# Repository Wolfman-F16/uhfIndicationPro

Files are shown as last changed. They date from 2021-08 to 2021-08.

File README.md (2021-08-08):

# UHF Indication Board Pro
This board and firmware can be used standalone or with the UHF Control Board RP.
The full potential is, of course, unlocked with the UHF Control Board RP.

The board can be communicated with using SPI, UART or I2C (not implemented).

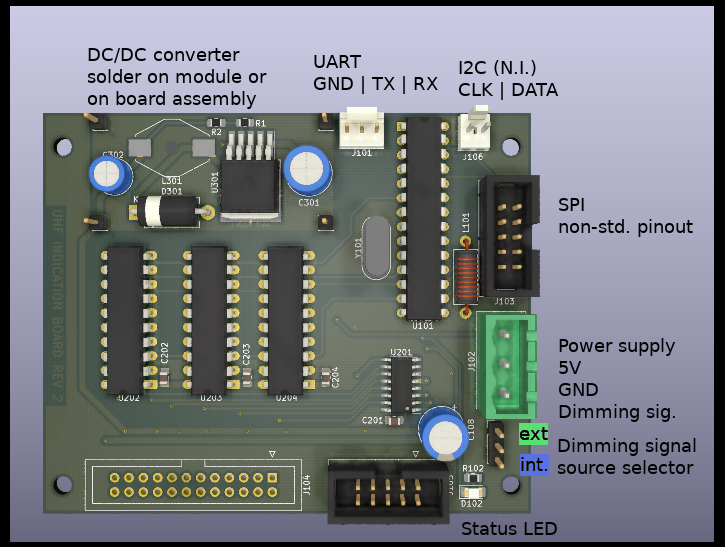
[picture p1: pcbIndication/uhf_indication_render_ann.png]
board with annotations


# AVR Fuse Bits
Use your ISP programmer of choice to set the fuse bits of the ATmega8 microcontroller. ATTENTION: the pinout of the board is not standard! Make sure you have a modified ribbon cable or use jumper wires to make the appropriate connections!

    avrdude -c <programmer> -p m8 -Ulfuse:v:0xfe:m -Uhfuse:v:0xd1:m

# Flashing Firmware

    avrdude -c <programmer> -p m8 -Uflash:v:UhfIndicationPro.<version>.hex

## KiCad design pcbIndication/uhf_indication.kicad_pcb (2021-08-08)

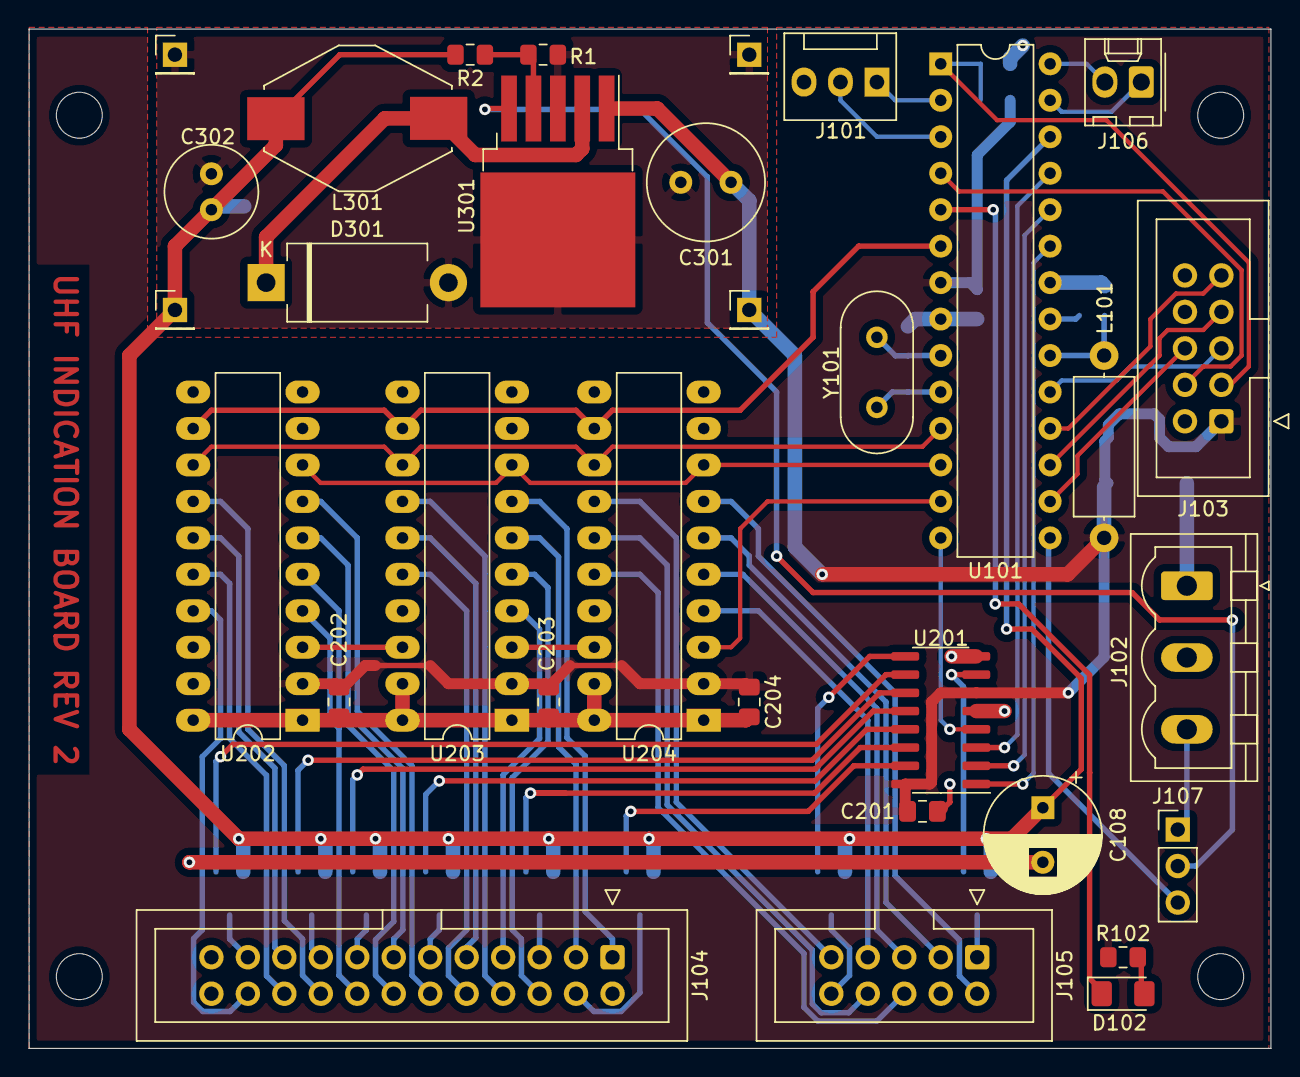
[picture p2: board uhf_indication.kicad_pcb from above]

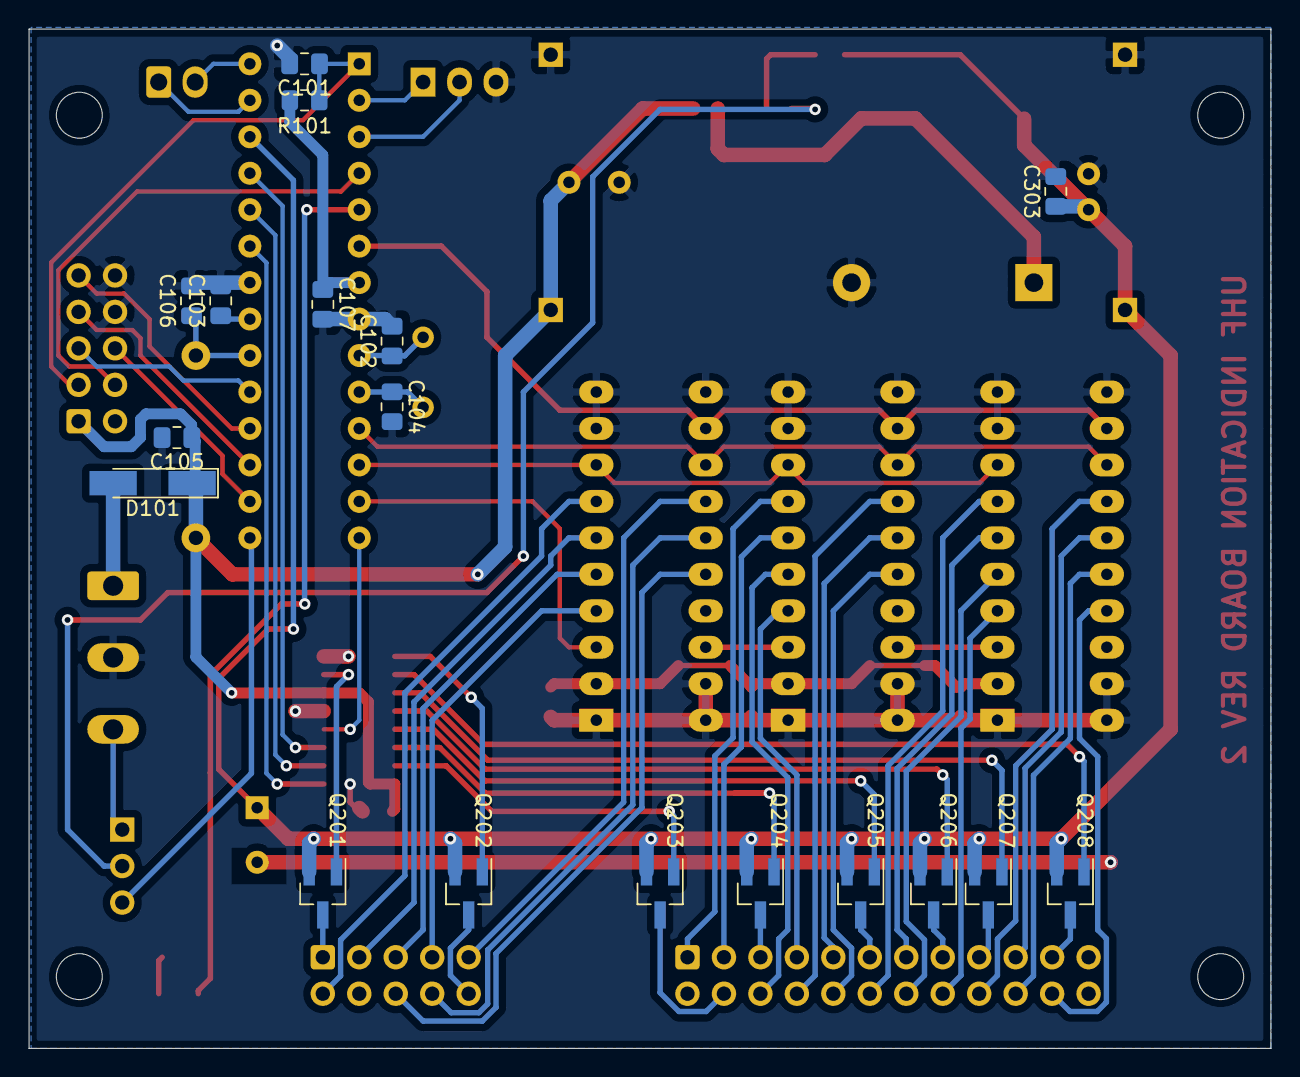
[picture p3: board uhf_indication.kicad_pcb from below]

Board: 2 copper layers, 86.5 x 71.0 mm, 54 parts (18 on the bottom side), 73 nets.

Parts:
C101, C103, C303: 10nF; C_0805_2012Metric_Pad1.18x1.45mm_HandSolder
C102, C104: 22p; C_0805_2012Metric_Pad1.18x1.45mm_HandSolder
C105, C106: 100pF; C_0805_2012Metric_Pad1.18x1.45mm_HandSolder
C107, C201, C202, C203, C204: 100nF; C_0805_2012Metric_Pad1.18x1.45mm_HandSolder
C108: 2.2uF; CP_Radial_D8.0mm_P3.80mm
C301: 470uF; C_Radial_D8.0mm_H7.0mm_P3.50mm
C302: 220uF; C_Radial_D6.3mm_H5.0mm_P2.50mm
D101: 2A SMD Fuse; D_MiniMELF_Handsoldering
D102: Green LED; LED_1206_3216Metric_Pad1.42x1.75mm_HandSolder
D301: 1N5825; D_DO-201_P12.70mm_Horizontal
H101, H102, H103, H104: MountingHole; MountingHole_3.2mm_M3
J101: UART; FanPinHeader_1x03_P2.54mm_Vertical
J102: Power; PhoenixContact_MSTBVA_2,5_3-G_1x03_P5.00mm_Vertical
J103: COMM; IDC-Header_2x05_P2.54mm_Vertical
J104: Frequency; IDC-Header_2x12_P2.54mm_Vertical
J105: Channel; IDC-Header_2x05_P2.54mm_Vertical
J106: I2C; Molex_KK-254_AE-6410-02A_1x02_P2.54mm_Vertical
J107: Power Control Select; PinHeader_1x03_P2.54mm_Vertical
J301: PWR_IN_P; PinHeader_1x01_P2.54mm_Vertical
J302: PWR_IN_GND; PinHeader_1x01_P2.54mm_Vertical
J303: PWR_OUT_P; PinHeader_1x01_P2.54mm_Vertical
J304: PWR_OUT_GND; PinHeader_1x01_P2.54mm_Vertical
L101: 10uH; L_Axial_L9.5mm_D4.0mm_P12.70mm_Horizontal_Fastron_SMCC
L301: 47uH; L_Fastron_PISN_Handsoldering
Q201, Q202, Q203, Q204, Q205, Q206, Q207, Q208: TSM2301ACX; SOT-23_Handsoldering
R1: 3k3; R_0805_2012Metric_Pad1.15x1.40mm_HandSolder
R2: 4k7; R_0805_2012Metric_Pad1.15x1.40mm_HandSolder
R101: 8k2; R_0805_2012Metric_Pad1.15x1.40mm_HandSolder
R102: 470R; R_0805_2012Metric_Pad1.15x1.40mm_HandSolder
U101: ATmega8-16PU; DIP-28_W7.62mm
U201: 74HC137; SOIC-16_3.9x9.9mm_P1.27mm
U202, U203, U204: TPIC6595; DIP-20_W7.62mm_LongPads
U301: LM2596S-ADJ; TO-263-5_TabPin3
Y101: 16 MHz; Crystal_HC49-U_Vertical

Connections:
+3V0: C108.1, C302.1, C303.1, J303.1, L301.2, Q201.2, Q202.2, Q203.2, Q204.2, Q205.2, Q206.2, Q207.2, Q208.2, R2.1, U101.26
/ADDR0: U101.23, U201.1
/ADDR1: U101.24, U201.2
/ADDR2: U101.25, U201.3
/AREF: C103.1, U101.21
/AVCC: C106.1, L101.1, U101.20
/D7_A: J105.6, U204.16
/D7_B: J105.3, U204.6
/D7_C: J105.5, U204.5
/D7_D: J105.9, U204.14
/D7_E: J105.7, U204.4
/D7_F: J105.8, U204.15
/D7_G: J105.2, U204.7
/D7_N1: J105.1, Q201.3
/D7_N2: J105.10, Q202.3
/D14_A: J104.9, U203.15
/D14_B: J104.13, U202.6
/D14_C: J104.6, U203.5
/D14_D: J104.8, U203.14
/D14_Dp: J104.10, U203.16
/D14_E: J104.12, U202.7
/D14_F: J104.7, U203.4
/D14_G1: J104.22, U202.17
/D14_G2: J104.20, U202.16
/D14_H: J104.1, U203.7
/D14_J: J104.3, U203.6
/D14_K: J104.19, U202.15
/D14_L: J104.18, U202.14
/D14_M: J104.16, U202.4
/D14_N: J104.14, U202.5
/Display Control/C01: Q202.1, U201.9
/Display Control/C10: Q201.1, U201.7
/Display Control/F1: Q203.1, U201.15
/Display Control/F2: Q204.1, U201.14
/Display Control/F3: Q205.1, U201.13
/Display Control/F4: Q206.1, U201.12
/Display Control/F5: Q207.1, U201.11
/Display Control/F6: Q208.1, U201.10
/I2C_SCL: J106.2, U101.28
/I2C_SDA: J106.1, U101.27
/MISO: J103.9, U101.18
/MOSI: J103.7, U101.17
/N1: J104.4, Q203.3
/N2: J104.5, Q204.3
/N3: J104.11, Q205.3
/N4: J104.15, Q206.3
/N5: J104.17, Q207.3
/N6: J104.21, Q208.3
/PWR_ENA: J107.2, U301.5
/PWR_ENA_EXT: J102.3, J107.1
/RX: J101.1, U101.2
/SCK: J103.5, U101.19
/SHF_RCK: U101.6, U202.12, U203.12, U204.12
/SHF_SCK: U101.11, U202.13, U203.13, U204.13
/SHF_SDA: U101.13, U204.3
/TRIGGER: J103.4, U101.4
/TX: J101.2, U101.3
/XTAL1: C102.1, U101.9, Y101.1
/XTAL2: C104.1, U101.10, Y101.2
/~MUX_ENA: U101.14, U201.4
/~RESET: C101.1, J103.3, R101.2, U101.1
/~SHF_CLR: U101.12, U202.8, U203.8, U204.8
/~SS: J103.6, U101.16
/~STATUS_LED: D102.1, U101.5
GND: C101.2, C102.2, C103.2, C104.2, C105.2, C106.2, C107.2, C108.2, C201.2, C202.2, C203.2, C204.2, C301.2, C302.2, C303.2, D301.2, J101.3, J102.2, J103.8, J103.10, J302.1, J304.1, R1.2, U101.8, U101.22, U201.5, U201.8, U202.1, U202.9, U202.10, U202.11, U202.19, U202.20, U203.1, U203.9, U203.10, U203.11, U203.19, U203.20, U204.1, U204.9, U204.10, U204.11, U204.19, U204.20, U301.3
unnamed: D101.2, J102.1
unnamed: D102.2, R102.2
unnamed: D301.1, L301.1, U301.2
unnamed: J107.3, U101.15
unnamed: R1.1, R2.2, U301.4
unnamed: U202.3, U203.18
unnamed: U203.3, U204.18
VCC: C105.1, C107.1, C201.1, C202.1, C203.1, C204.1, C301.1, D101.1, J103.1, J301.1, L101.2, R101.1, R102.1, U101.7, U201.6, U201.16, U202.2, U203.2, U204.2, U301.1

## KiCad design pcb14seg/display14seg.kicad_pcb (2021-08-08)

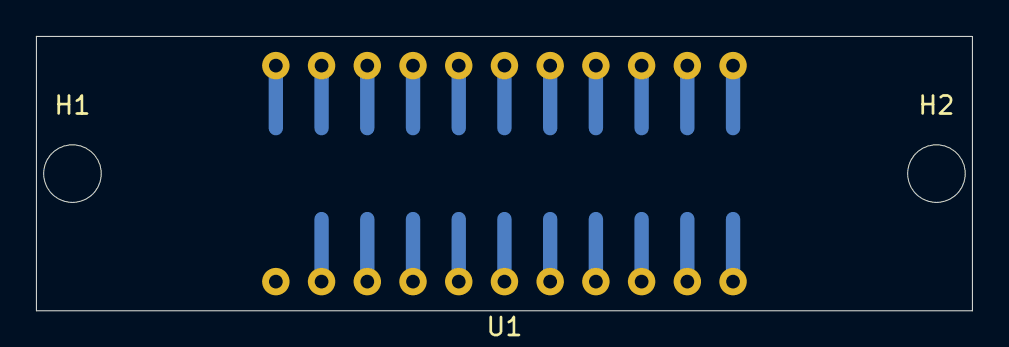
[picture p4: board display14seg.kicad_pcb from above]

Board: 2 copper layers, 52.0 x 15.2 mm, 4 parts (1 on the bottom side), 21 nets.

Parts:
H1, H2: MountingHole; MountingHole_3.2mm_M3_DIN965
J1: Conn_02x11_Odd_Even; PinHeader_2x11_P2.54mm_Vertical_SMD
U1: D60401CS

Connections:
/N1: J1.4, U1.2
/N2: J1.5, U1.20
/N3: J1.11, U1.17
/N4: J1.15, U1.15
/N5: J1.17, U1.14
/N6: J1.21, U1.12
/P1: J1.9, U1.18
/P2: J1.13, U1.16
/P3: J1.6, U1.3
/P4: J1.8, U1.4
/P5: J1.12, U1.6
/P6: J1.7, U1.19
/P7: J1.22, U1.11
/P8: J1.20, U1.10
/P9: J1.1, U1.22
/P10: J1.3, U1.21
/P11: J1.19, U1.13
/P12: J1.18, U1.9
/P13: J1.16, U1.8
/P14: J1.14, U1.7
/P15: J1.10, U1.5

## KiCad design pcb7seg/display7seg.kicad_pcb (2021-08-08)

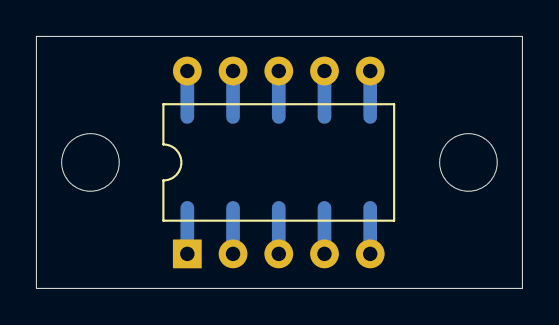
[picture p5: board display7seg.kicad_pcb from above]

Board: 2 copper layers, 27.0 x 14.0 mm, 4 parts (1 on the bottom side), 10 nets.

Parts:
H101, H102: MountingHole; MountingHole_3.2mm_M3_DIN965
J1: SMD Conn; PinHeader_2x05_P2.54mm_Vertical_SMD
U1: CL03621A; DIP-10_W10.16mm

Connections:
/PIN_1: J1.9, U1.1
/PIN_2: J1.7, U1.2
/PIN_3: J1.5, U1.3
/PIN_4: J1.3, U1.4
/PIN_5: J1.1, U1.5
/PIN_6: J1.2, U1.6
/PIN_7: J1.4, U1.7
/PIN_8: J1.6, U1.8
/PIN_9: J1.8, U1.9
/PIN_10: J1.10, U1.10

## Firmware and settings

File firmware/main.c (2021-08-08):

/* Name: main.c
 * Project: UHFIndicationPro
 * Author: Wolfgang Engelhard
 *
 *  License: GPL v2
 */
#ifndef F_CPU
#error F_CPU not defined
#endif

#include <avr/io.h>
#include <avr/interrupt.h>
#include <avr/sleep.h>
#include <avr/eeprom.h>

#include "uhfIndication.h"
#include "adc.h"
#include "serial.h"
#include "terminal.h"
#include "spi.h"
#include "timer.h"
#include "shift.h"
#include "font.h"

extern void checkEeprom(void);

/* ------------------------------------------------------------------------- */
int main(void) {
  uint8_t i = 0;
  uint8_t isCBconnected = FALSE;
  // display voltage monitoring
  uint16_t adcValue = 0;

  status.boot = 1;

  // init IO
  initIO();
  if (!(PINB & (1 << PIN_SPI_SS))) {// if SS still high and not pulled down by control board...
    isCBconnected = 0x01;
  }

 // checkEeprom();

  // init ADC
  initAdc();
  if (!(PINB & (1 << PIN_SPI_SS))) {// if SS still high and not pulled down by control board...
    isCBconnected |= 0x02;
  }
  // dummy read first ADC value
  startAdcConversion();
  wait4Adc2Complete();
  adcValue = ADCW;
  // init SPI
  initSpi();
  // enable interrupts
  sei();
  // init UART
  initSerial();
  sendUartByte(NEWPAGE);

  if (!(PINB & (1 << PIN_SPI_SS))) {// if SS still high and not pulled down by control board...
    isCBconnected |= 0x04;
  }
  // init Timer
  initTimer();
  if (!(PINB & (1 << PIN_SPI_SS))) {// if SS still high and not pulled down by control board...
    isCBconnected |= 0x08;
  }
  setDefaults();

  if (isCBconnected > 0) {// if SS still high and not pulled down by control board...
    setLightBlank();
  } else {
    setLightTestOn();           // start display up with led test
    updateDisplay();                  /* this now loads test into shift registers */
    acceptByte();                     /* this shows shift data to outputs */
  }
  enableTimer2();                   /* this charlie plexes the digits */

  // init complete

  uint8_t *radioArray = (uint8_t*) &radio;
#if EEPROM_DATA_AVAIL > 0
  // load eeprom values to sram
  for (i = 0; i < 128; i++) {
    asciiTable[i] = eeprom_read_byte(table + i);
  }
  // write radio variable using sram data
  for (i = 0; i < sizeof(radio_t); i++) {
    radioArray[i] = asciiTable[i];
  }
#else
  for (i = 0; i < sizeof(radio_t); i++) {
    radioArray[i] = RADIO_INIT_DATA[i];
  }
#endif
  if (radio.day == TRUE) {
    OCR1A = radio.brightnessDay << 2;
  } else {
    OCR1A = radio.brightnessNight << 2;
  }
  printVersion();
  sendUartBits(radio.version);    // debug
  // wait till init phase is complete ~1 sec.
  if (isCBconnected == FALSE) {
    while (status.updateTimer != TRUE)
      asm("nop");

    setLightTestOff();          // stop display test
    sendUartByte('_');
  } else {
    sendUartByte('~');
    sendUartBits(isCBconnected);
  }
  status.boot = 0;
  status.updateDisplay = 1;
  sendUartByte('\n');
  /****************************** main event loop ****************************/
  BEGIN_INFINITE_LOOP
    if (status.updateDisplay) {
      status.updateDisplay = 0;
      if (isCBconnected > 0) {
        setStatusLedOff(); /* only turn off LED when control board is connected */
      }
      updateDisplay();
    }

    // serial terminal
    if (serialStatus.rx) {
      serialStatus.rx = FALSE;
      processUart(rxValue);
    }

    // voltage monitoring
    if (status.updateAdc) {
      status.updateAdc = FALSE;

      adcValue = currentAdcValue;
    }
  END_INFINITE_LOOP

  return 0;
}

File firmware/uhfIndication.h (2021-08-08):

/*
 * UHFIndication.h
 *
 *  Created on: 30.01.2010
 *      Author: Wolfman
 */

#ifndef UHFINDICATION_H_
#define UHFINDICATION_H_

#include "adc.h"
#include "spi.h"

#include <avr/io.h>
#include <stdint.h>

#define _DEBUG_ 0

#ifndef EEMEM
#define EEMEM  __attribute__ ((section (".eeprom")))
#endif

#define BEGIN_INFINITE_LOOP for(;;) {
#define END_INFINITE_LOOP   }

#define TRUE            1
#define FALSE           0

/*----------------------------------------------------------------------------*/
// I/O
/*----------------------------------------------------------------------------*/
#define PORT_OUT_SHFT   PORTD

#define PIN_SHFT_RCK    PORTD4
#define PIN_SHFT_DAT    PORTD7
#define PIN_SHFT_SCK    PORTD5
#define PIN_SHFT_CLR    PORTD6

#define PORT_OUT_MUX_ENA    PORTB
#define PIN_MUX_ENA         PORTB0

#define PORT_OUT_MUX    PORTC
#define PIN_MUX_ADDR0   PORTC0
#define PIN_MUX_ADDR1   PORTC1
#define PIN_MUX_ADDR2   PORTC2
#define PORT_MUX_MASK   0x07


#define PORT_LED        PORTD
#define PIN_STATUS_LED  PORTD3

#define PORT_OUT_PWM    PORTB
#define PIN_PWM         PORTB1

#define PIN_TRIGGER     PORTD2

#define PIN_SPI_CLK     PORTB5
#define PIN_SPI_MISO    PORTB4
#define PIN_SPI_MOSI    PORTB3
#define PIN_SPI_SS      PORTB2
#define PIN_RX          PORTD0
#define PIN_TX          PORTD1

/*----------------------------------------------------------------------------*/
// UHF
/*----------------------------------------------------------------------------*/
// reserve mem for partial ASCII table
#define MAX_BYTE        0x5A
#define CHANNEL_LENGTH  2
#define FREQ_LENGTH     6
#define BYTE_LENGTH     8

#define CHANNEL_OFFSET  7
/* 7 seg displays*/
#define BLANK_DIGIT     0xFF
#define TEST_DIGIT      ~0x7F
#define DECIMAL_POINT   0x80
/* 14 seg displays */
#define BLANK16_DIGIT   0xFFFF
#define TEST16_DIGIT    0x0040
#define DECIMAL16_POINT 0x0040

/*----------------------------------------------------------------------------*/
// UART
/*----------------------------------------------------------------------------*/
// parser
#define NEWLINE         '\r'
#define NEWPAGE         0x0C
#define BACKSPACE       0x7F
#define TERMINATOR      0x00

#define MAX_BUFFER_SIZE 20
#define MAX_MSG_LENGTH  25
#define MAX_MESSAGES    9
#define MAX_COMMANDS    5
// error codes for TTYFlag (number specifies bit)
#define ERROR_OK        0
#define ERROR_BUFFER    1
#define ERROR_CMD       2
#define ERROR_PARAM     3
// commands
#define CMD_B           1
#define CMD_C           2
#define CMD_D           3
#define CMD_F           4
#define CMD_INFO        5

/*----------------------------------------------------------------------------*/
// SPI
/*----------------------------------------------------------------------------*/
//indicates start of frame
#define MSG_TYPE        0x1A
// for channel & frequency for starters.
#define MAX_SPI_BUFFER  8

/*----------------------------------------------------------------------------*/
// SW Timer
/*----------------------------------------------------------------------------*/
#define SWT_ADC_ISR     0
#define SWT_TEST_ISR    1
#define SWT_CHARLIE_ISR 2

/****************************   Structures      *******************************/
typedef struct {
  uint8_t channelString[CHANNEL_LENGTH];
  uint8_t frequencyString[FREQ_LENGTH];
  uint8_t brightnessDay;
  uint8_t brightnessNight;
  uint8_t day;
  uint8_t version;
} radio_t;


typedef struct {
  unsigned boot:1;
  unsigned updateAdc:1;
  unsigned updateTimer:1;
  unsigned updateDisplay:1;
  unsigned currFrequency:3;
  unsigned currChannel:1;
} status_t;

/****************************   Variables       *******************************/
volatile radio_t radio;
volatile status_t status;
volatile uint8_t currentAdcValue;

extern uint8_t asciiTable[128];
extern uint8_t table[] EEMEM;

extern volatile uint8_t swTimer[3];

/****************************   FUNCTION DECLARATIONS ************************/
void initIO(void);
void setDefaults(void);

void updateDisplay(void);

void setLightTestOn(void);
void setLightTestOff(void);
void setLightBlank(void);

/****************************   INLINE FUNCTIONS    **************************/
/*
 * sets status led off
 */
static inline void setStatusLedOff()
{
  PORT_LED |= _BV(PIN_STATUS_LED);
}

/*
 * sets status led on
 */
static inline void setStatusLedOn()
{
  PORT_LED &= ~_BV(PIN_STATUS_LED);
}

/*
 * set charlie plexing address
 */
static inline void charlieplex(uint8_t index)
{
  PORTC &= ~PORT_MUX_MASK;
  PORTC |= index & PORT_MUX_MASK;
}

/**************************** Interrupt Service Routine     ******************/
/**
 * interrupt service routine
 *
 * Display test
 */
static inline void isrTestTimer()
{
  static uint8_t timer0Ext = 0x2F;

  if(timer0Ext > 0) {
    timer0Ext--;
  } else {
    // notify main loop
    status.updateTimer = TRUE;
  }
}

/**
 * interrupt service routine
 *
 * ADC conversion
 */
static inline void isrAdc()
{
  startAdcConversion();
}

/**
 * interrupt service routine
 *
 * charlie plexing
 */
static inline void isrCharlieplex()
{
  if (swTimer[SWT_CHARLIE_ISR] == 0) {
    swTimer[SWT_CHARLIE_ISR] = 8;
    charlieplex(CHANNEL_OFFSET - status.currChannel);
    status.currChannel++;
    if (status.currChannel >= CHANNEL_LENGTH) {
      status.currChannel = 0;
    }
  } else {
    swTimer[SWT_CHARLIE_ISR]--;
    charlieplex(status.currFrequency);
    status.currFrequency++;
    if (status.currFrequency >= FREQ_LENGTH) {
      status.currFrequency = 0;
    }
  }
  status.updateDisplay = 1;
}



/**/
/**
 * interrupt service routine
 *
 * SPI communication
 */
static inline void isrSpi(void)
{
  static uint8_t radioIndex = 0;
  uint8_t *radioArray = (uint8_t*)& radio;

  spiRxValue = SPDR;
  /* debug */
  UDR = spiRxValue;
  /* debug */
  if(spiRxValue == SPI_SOF) {
    radioIndex = 0;
    setStatusLedOn();
    return;
  }
  if(radioIndex < (CHANNEL_LENGTH + FREQ_LENGTH)) {
    if(spiRxValue == ' ') {
      spiRxValue = 'X';  // whitespace conversion
    }
    radioArray[radioIndex++] = spiRxValue;
  }
}
#endif /* UHFINDICATION_H_ */
